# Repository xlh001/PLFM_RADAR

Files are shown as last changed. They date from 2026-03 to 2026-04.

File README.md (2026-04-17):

# AERIS-10: Open Source Pulse Linear Frequency Modulated Phased Array Radar








AERIS-10 Radar System

AERIS-10 is an open-source, low-cost 10.5 GHz phased array radar system featuring Pulse Linear Frequency Modulated (LFM) modulation. Available in two versions (3km and 20km range), it's designed for researchers, drone developers, and serious SDR enthusiasts who want to explore and experiment with phased array radar technology.

AERIS-10 Antenna Array

## 📡 Overview

The AERIS-10 project aims to democratize radar technology by providing a fully open-source, modular, and hackable radar system. Whether you're a university researcher, a drone startup, or an advanced maker, AERIS-10 offers a platform for experimenting with beamforming, pulse compression, Doppler processing, and target tracking.

## 🔬 Key Features

- **Open Source Hardware & Software** - Complete schematics, PCB layouts, firmware, and software available
- **Dual Version Availability**:
  - **AERIS-10N (Nexus)**: 3km range with 8x16 patch antenna array
  - **AERIS-10E (Extended)**: 20km range with 32x16 dielectric-filled slotted waveguide array
- **Full Electronic Beam Steering** - ±45° electronic steering in elevation and azimuth
- **Advanced Signal Processing** - On-board FPGA handles pulse compression, Doppler FFT, MTI, and CFAR
- **Python GUI** - User-friendly interface with map integration
- **GPS/IMU Integration** - Real-time position and attitude correction
- **Modular Design** - Separate power management, frequency synthesis, and RF boards

## 🏗️ System Architecture

AERIS-10 System Diagram

### Hardware Components

The AERIS-10 main sub-systems are:

- **Power Management Board** - Supplies all necessary voltage levels to the electronics components with proper filtering and sequencing (sequencing ensured by the microcontroller)

- **Frequency Synthesizer Board** - Uses a high-performance Low Jitter Clock Generator (AD9523-1) that supplies phase-aligned clock references for:
  - RX and TX Frequency Synthesizers (ADF4382)
  - DAC
  - ADC
  - FPGA

- **Main Board** containing:
  - **DAC** - Generates the RADAR Chirps
  - **2x Microwave Mixers (LT5552)** - For up-conversion and IF-down-conversion
  - **4x 4-Channel Phase Shifters (ADAR1000)** - For RX and TX chain beamforming
  - **16x Front End Chips (ADTR1107)** - Used for both Low Noise Amplifying (RX) and Power Amplifying (TX) stages
  - **XC7A50T FPGA** - Handles RADAR Signal Processing on the upstream FTG256 board:
    - PLFM Chirps generation via the DAC
    - Raw ADC data read
    - Digital Gain Control (host-configurable gain shift)
    - I/Q Baseband Down-Conversion
    - Decimation
    - Filtering
    - Forward FFT
    - Pulse Compression
    - Doppler, MTI and CFAR processing
    - USB Interface
  - **STM32F746xx Microcontroller** - Used for:
    - Power-up and power-down sequencing (see Power Management Excel File)
    - FPGA communication
    - Setup and Interface with:
      - Clock Generator (AD9523-1)
      - 2x Frequency Synthesizers (ADF4382)
      - 4x 4-Channel Phase Shifters (ADAR1000) for RADAR pulse sequencing
      - 2x ADS7830 8-channel I²C ADCs (Main Board, U88 @ 0x48 / U89 @ 0x4A) for 16x Idq measurement, one per PA channel, each sensed through a 5 mΩ shunt on the PA board and an INA241A3 current-sense amplifier (x50) on the Main Board
      - 2x DAC5578 8-channel I²C DACs (Main Board, U7 @ 0x48 / U69 @ 0x49) for 16x Vg control, one per PA channel; closed-loop calibrated at boot to the target Idq
      - GPS module (UM982) for GUI map centering and per-detection position tagging
      - GY-85 IMU for pitch/roll correction of target coordinates
      - BMP180 Barometer
      - Stepper Motor
      - 1x ADS7830 8-channel I²C ADC (Main Board, U10) reading 8 thermistors for thermal monitoring; a single GPIO (EN_DIS_COOLING) switches the cooling fans on when any channel exceeds the threshold
      - RF switches

- **16x Power Amplifier Boards** - Used only for AERIS-10E version, featuring 10Watt QPA2962 GaN amplifier for extended range

- **Antenna Arrays**:
  - **AERIS-10N (Nexus)** - 8x16 patch antenna array
  - **AERIS-10X (Extended)** - 32x16 dielectric-filled slotted waveguide antenna array

- **Miscellaneous Components**:
  - Slip-Ring
  - Stepper Motor and drivers
  - Cooling Fans
  - Enclosure

### Processing Pipeline

1. **Waveform Generation** - DAC creates LFM chirps
2. **Up/Down Conversion** - LT5552 mixers handle frequency translation
3. **Beam Steering** - ADAR1000 phase shifters control 16 elements
4. **Signal Processing (FPGA)**:
   - Raw ADC data capture
   - I/Q baseband down-conversion
   - Decimation & filtering (CIC/FIR)
   - Pulse compression
   - Doppler FFT processing
   - MTI & CFAR detection
5. **System Management (STM32)**:
   - Power sequencing
   - Peripheral configuration
   - GPS/IMU integration
   - Stepper motor control
6. **Visualization (Python GUI)**:
   - Real-time target plotting
   - Map integration
   - Radar control interface

AERIS-10 GUI Demo

## 📊 Technical Specifications

| Parameter | AERIS-10N (Nexus) | AERIS-10X (Extended) |
|---|---|---|
| **Frequency** | 10.5 GHz | 10.5 GHz |
| **Max Range** | 3 km | 20 km |
| **Antenna** | 8x16 Patch Array | 32x16 Slotted Waveguide |
| **Beam Steering** | Electronic (±45°) | Electronic (±45°) |
| **Mechanical Scan** | 360° (stepper motor) | 360° (stepper motor) |
| **Output Power** | ~1W×16 | 10W×16 (GaN amplifier) |
| **Processing** | FPGA + STM32 | FPGA + STM32 |

## 🚀 Getting Started

### 🧹 Repository File Placement Policy

To keep the repository root clean and make artifacts easy to find, place generated files in the following locations:

- **Published reports (tracked, GitHub Pages):** `docs/`
  - Example: `docs/AERIS_Simulation_Report_v2.pdf`
- **Simulation-generated outputs (local, gitignored):** `5_Simulations/generated/`
  - Plots, scenario outputs, temporary analysis directories
- **FPGA/Vivado generated artifacts (local, gitignored):** `9_Firmware/9_2_FPGA/reports/`
  - VCD/VVP dumps, temporary CSVs, local report snapshots
- **Reusable FPGA automation scripts (tracked):** `9_Firmware/9_2_FPGA/scripts/`
  - TCL flows, helper scripts used by build/bring-up

**Do not leave generated artifacts in the repository root.**

### Prerequisites

- Basic understanding of radar principles
- Experience with PCB assembly (for hardware build)
- Python 3.8+ for the GUI software
- FPGA development tools (Vivado) for signal processing modifications

### Hardware Assembly

1. **Order PCBs**: Production outputs are under `/4_Schematics and Boards Layout/4_7_Production Files`
2. **Source Components**: BOM/CPL files are co-located under `/4_Schematics and Boards Layout/4_7_Production Files`
3. **Assembly**: Use the schematics in `/4_Schematics and Boards Layout/4_6_Schematics` together with the production outputs above; a standalone assembly guide is not currently tracked
4. **Antenna**: Choose appropriate array files for your target variant
5. **Enclosure**: Mechanical drawings currently live in `/8_Utils/Mechanical_Drawings`

## 📜 License

This project is open-source but uses **different licenses for hardware and software** to ensure proper legal coverage.

### Hardware Documentation
The hardware design files—including:
- Schematics and PCB layouts (in `/4_Schematics and Boards Layout`)
- Bill of Materials (BOM) files
- Gerber files and manufacturing outputs
- Mechanical drawings and enclosure designs

are licensed under the **CERN Open Hardware Licence Version 2 – Permissive (CERN-OHL-P)** .

This is a hardware-specific license that:
- ✅ Clearly defines "Hardware," "Documentation," and "Products"
- ✅ Includes explicit patent protection for contributors and users
- ✅ Provides stronger liability limitations (important for high-power RF)
- ✅ Aligns with professional open-hardware standards (CERN, OSHWA)

You may use, modify, and sell products based on these designs, provided you:
- Maintain the original copyright notices
- Distribute any modified designs under the same license
- Make your modifications available in Source format

### Software and Firmware
The software components—including:
- FPGA code (VHDL/Verilog in `/9_Firmware`)
- Microcontroller firmware (STM32)
- Python GUI and utilities

remain under the **MIT License** for maximum flexibility.

### Full License Texts
- The complete CERN-OHL-P license text is in the `LICENSE` file
- MIT license terms apply to software where not otherwise specified

### Why This Change?
Originally, the entire project used the MIT license. The community (special thanks to gmaynez!) pointed out that MIT lacks legal protections needed for physical hardware. The switch to CERN-OHL-P ensures the project is properly protected while maintaining the same permissive spirit.

## 📚 Documentation

Comprehensive documentation is available in the `/docs` folder and served via GitHub Pages at [https://NawfalMotii79.github.io/PLFM_RADAR/docs/](https://NawfalMotii79.github.io/PLFM_RADAR/docs/):

- [System Architecture](/docs/architecture.html)
- [Implementation Log](/docs/implementation-log.html)
- [Hardware Bring-Up Guide](/docs/bring-up.html)
- [Test Reports](/docs/reports.html)
- [Release Notes](/docs/release-notes.html)

## 🤝 Contributing

We welcome contributions! Please see our [Contributing Guidelines](/CONTRIBUTING.md) for details on repo layout, branch workflow, and basic PR checks.

Areas where help is especially appreciated:
- **RF Engineers**: Review designs, optimize antenna performance
- **FPGA Developers**: Optimize signal processing pipeline
- **Software Developers**: Enhance Python GUI and SDK
- **Beta Testers**: University researchers, drone startups, advanced makers

## 📞 Contact & Collaboration

I welcome serious inquiries from researchers, engineers, and potential collaborators. However, due to the high volume of interest in this project, please understand that I cannot guarantee a response to every message.

- **Technical questions or bug reports**: Please [open a GitHub issue](https://github.com/NawfalMotii79/PLFM_RADAR/issues) so the whole community can benefit from the discussion.
- **Collaboration, licensing, or business inquiries**: 📧 nawfal.motii.33 [at] gmail [dot] com

## 💰 Sponsors

PCBWay Sponsor Logo

---

**Star ⭐ this repository if you're interested in open-source radar technology!**

*Note: This is an active development project. Some features are still in progress. Check the issues page for known limitations and upcoming features.*

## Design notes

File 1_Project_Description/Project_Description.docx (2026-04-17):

TITLE: Open Source Pulse Linear Frequency Modulated Phased Array RADAR
Reference:
Date:
Original Proposal Date:

## 1.0 PROJECT DESCRIPTION

An open-source, low-cost 10.5 GHz phased array radar with phased array antenna and Pulse LFM modulation—available in 3km and 20km range versions. For researchers, drone developers, and serious SDR enthusiasts.

## 2.0 TECHNICAL SPECIFICATIONS

### 2.1 System Architecture Overview

- The AERIS-10 comes in 2 versions:
  - AERIS-10N (Nexus) with Range up to 3Km
  - AERIS-10X (Extended) with scanning Range up to 20Km
- Frequency: 10.5GHz
- Antenna Type: 8x16 patch antenna array for the Nexus and 32x16 dielectric-filled slotted waveguide antenna array for the Extended version.
- Electronically controlled Elevation and Azimuth Beam steering. (The prototype uses the 16 antenna elements to steer the Elevation beam and the Azimuth is performed using a stepper motor; but the designed system can be hacked to control both Elevation and Azimuth electronically.
- Output: Range & Doppler of Multi-Targets
- Interface: A GUI written in Python

Current Status: Alpha Prototype

For sake of testing, validating and optimizing the cost of the prototype, this late has been designed using one PCB for:
- The Power supply management
- The Digital components
- The Analog and mixed signal components
- The RF parts

This won’t be the case for the mass production system, where separated modules would be used to reduce EMI and enhance the signals integrity; also a more professional clock source and frequency synthesizer would be used. The new schematics, PCB layout and firmware are already available

Understanding the System Hardware:

The AERIS-10 main sub-systems are:

- A Power Management Board that supplies all the necessary voltage levels to the electronics components with proper filtering and sequencing (This late is ensured by the microcontroller)
- A Frequency Synthesizer Board using a high performance Low Jitter Clock Generator (AD9523-1) that supplies phased aligned clock references for the:
  - RX and TX Frequency Synthesizers (ADF4382)
  - DAC
  - ADC
  - FPGA
- A Main Board containing:
  - A DAC to generate the RADAR Chirps
  - 2 Microwave Mixers (LT5552) for up-conversion and IF-down-conversion
  - 4 4-Channels Phase Shifters (ADAR1000) for the RX and TX chain
  - 16 Front End chips (ADTR1107) used for Both Low Noise Amplifying (RX) and Power Amplifying (TX) Stages
  - An XC7A100T FPGA used for RADAR Signal Processing:
    - PLFM Chirps generation via the DAC
    - Raw ADC data read
    - AGC
    - I/Q Baseband Down-Conversion
    - Decimation
    - Filtering
    - Forward FFT
    - Pulse Compression
    - Doppler, MTI and CFAR processing
    - USB Interface
  - An STM32F746xx Microcontroller used to:
    - Ensure the proper powering up and down sequencing (Check the Power Management Excel File)
    - Communicate with the FPGA
    - Setup and Interface with the following components:
      - The Clock Generator (AD9523-1)
      - The 2 Frequency Synthesizers (ADF4382)
      - The 4 4-Channels Phase Shifters (ADAR1000) for proper RADAR pulse sequencing
      - The 2 ADS7830 ADCs used on the 16 Power Amplifier Boards to measure Idq
      - The 2 DAC5578 used on the 16 Power Amplifier Boards to control Vg
      - The GPS used to set the center of the map on the GUI
      - The GY_85 IMU to apply pitch and roll correction to the processed target longitude and latitude
      - The BMP180 Barometer
      - The Stepper Motor
      - The 8 ADS7830 Temperature Sensors used to activate the Cooling Fans
      - RF switches
- 16 Power Amplifier Boards used only for the AERIS-10E where a 10Watt QPA2962 GaN amplifier has been chosen to extend the RADAR Range
- 8x16 patch antenna array board for the Nexus and 32x16 dielectric-filled slotted waveguide antenna array for the Extended version
- Miscellaneous (Slip-Ring, Stepper Motor and its drivers, Cooling Fan, Enclosure…)

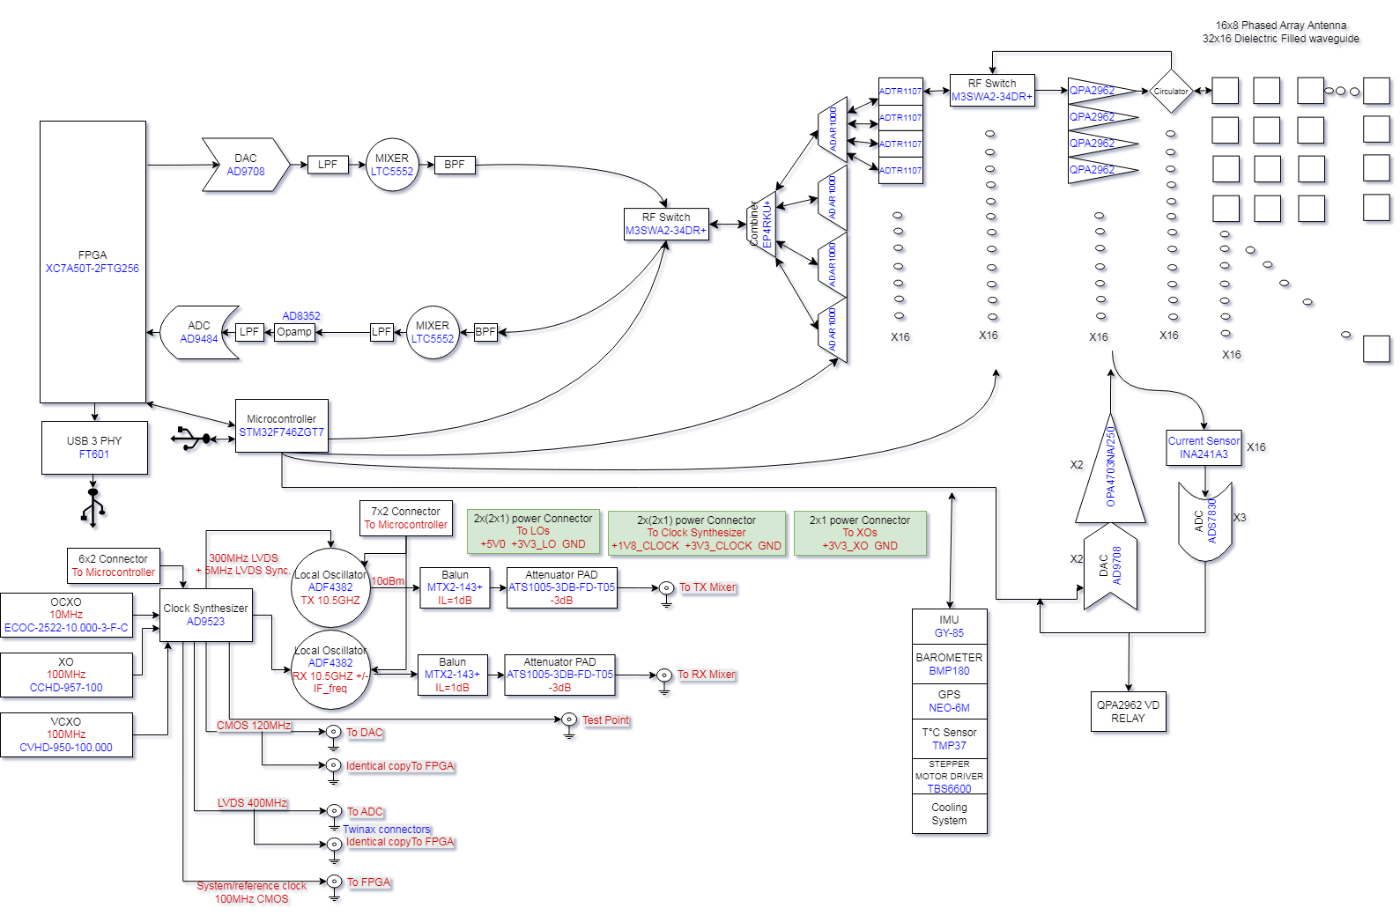
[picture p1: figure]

### 2.4 Software & Processing

The AERIS-10 radar system is built around three core processing elements working in concert: an STM32 microcontroller handling system management and peripherals, an FPGA executing real-time signal processing, and a Graphical User Interface (GUI) for user control and data visualization. The following describes the complete boot sequence and operational loop that governs how the system wakes, calibrates, and begins scanning.

### System Boot and Initialization

When power is first applied, the STM32 microcontroller begins a carefully sequenced startup routine designed to bring all subsystems online in the correct order, ensuring stable power and clock references before any RF activity begins.

The first critical step is waiting for the OCXO (Oven-Controlled Crystal Oscillator) to reach thermal stability. This high-precision frequency reference requires approximately three minutes to warm up and stabilize—without this wait, the entire radar's frequency accuracy would drift, compromising range resolution and target detection.

Once the OCXO is stable, the STM32 manages voltage sequencing for the system's clock generator, the AD9523. This ensures that power rails reach their correct levels in the proper order before the device is initialized. The STM32 then configures the AD9523, setting up the planned clock distribution that will drive the FPGA and all RF components with precise, phase-aligned timing.

With clocks established, the STM32 sequences power for the FPGA itself, then proceeds to initialize the remaining peripheral systems:

- The GPS module begins acquiring satellite locks
- The IMU (Inertial Measurement Unit) and barometer are initialized for attitude and altitude sensing
- Two ADF4382 frequency synthesizers (one for transmit, one for receive) are configured
- Four ADAR1000 beamforming chips are initialized to control the 16 phased array elements

At this point, all hardware is ready and the system enters a waiting state, listening for the start command from the GUI.

### GUI Connection and System Arming

The operator interacts with the system through a custom Graphical User Interface running on a connected computer. When the user is ready to begin operation, they press the Start button on the GUI.

The GUI immediately transmits a specific start flag packet to the STM32—a predefined sequence of bytes {23, 46, 158, 237} that serves as a handshake to confirm communication is established. Following this flag, the GUI sends the full operational settings for the upcoming radar scan (waveform parameters, scan pattern, range settings, etc.).

The STM32 acknowledges these settings and begins actively monitoring the GPS data stream. It waits for a valid data lock, then begins sending modulated position streams back to the GUI containing longitude, latitude, and altitude information. The GUI receives these streams and uses the coordinates to center its map display on the radar's current location—giving the operator immediate spatial context for any detected targets.

### Attitude Determination and Mechanical Alignment

While maintaining GPS position updates, the STM32 continuously reads raw data from the IMU and barometer. It processes the IMU data to calculate pitch, roll, and yaw angles, while the barometer provides a secondary altitude reference.

With yaw (heading) known, the STM32 commands the stepper motor to rotate the antenna assembly to align with yaw = 0° (typically true north or a defined reference). This mechanical alignment ensures that all subsequent electronically-steered beams are referenced to a consistent absolute direction.

### Transmit and Receive Chain Configuration

Before any radar pulses are sent, the RF front-end must be precisely tuned. The STM32 configures the two ADF4382 frequency synthesizers—one set to the transmit frequency, the other to the receive frequency. Critically, it then executes a phase synchronization routine between these two synthesizers, ensuring that transmit and receive local oscillators are phase-coherent. This coherence is essential for Doppler processing and coherent pulse compression.

### The Scanning Loop: A Three-Level Nested Structure

The AERIS-10's scanning pattern is organized as a three-level nested loop, controlling:

1. Chirp sequence index (m) – Individual frequency ramps within a burst
2. Beam steering index (n) – Electronic steering across 32 elevation/azimuth positions
3. Mechanical azimuth index (y) – Physical rotation across 50 positions per revolution

This structure allows the system to build a complete volumetric scan through a combination of electronic beam steering (fast, within the pulse repetition interval) and mechanical rotation (slow, covering 360 degrees).

#### Loop Variables Defined

- m = Chirp number within a burst. Each burst consists of 32 chirps, organized as: *16 chirps at PRF1 (pulse repetition frequency 1) with duration T1, followed by a guard interval of 175.4µs, then 16 chirps at PRF2 with duration T2*
- n = Electronic steering index, ranging from 1 to 32. This corresponds to beam positions in elevation (or azimuth, depending on scan mode), controlled by phase settings on the ADAR1000 beamforming chips.
- y = Mechanical azimuth index, ranging from 1 to 50. The stepper motor moves the antenna to 50 discrete positions per full revolution, providing mechanical scanning in azimuth while electronics handle fast steering in the orthogonal plane.

### The Operational Loop

The loop begins with the STM32 commanding the stepper motor to move to the first azimuth position (y=1). Once the mechanical position is settled:

1. The STM32 sets the ADAR1000 phase shifters to the values corresponding to beam position n
2. It manages voltage sequencing for the ADTR1107s (RF switches) and the RF power amplifiers, ensuring they power up cleanly
3. It sends a flag to the FPGA indicating transmit mode and configures the ADAR1000s for transmission
4. The FPGA generates the chirp waveform through its DAC, driving the transmit array
5. Immediately after transmission, the FPGA signals the STM32 to switch to receive mode
6. The STM32 reconfigures the ADAR1000s for reception
7. The FPGA captures the returning echoes through its ADCs and begins the signal processing pipeline:
  - Down-conversion of the IF signal to baseband
  - Filtering
  - Extraction of I/Q components (using CIC filters, FIR filters, and NCO)
  - Pulse compression
  - Per-range Doppler FFT
  - Moving Target Indication (MTI)
  - Constant False Alarm Rate (CFAR) detection
  - Emission of detection reports (including small Range-Doppler thumbnails)
8. Processed radar data is sent from the FPGA to the GUI via FTDI interface
9. The GUI receives the data and updates its plots in real-time, displaying detected targets overlaid on the map

### Loop Iteration and Scan Completion

After completing the processing for chirp m, the system increments m and returns to step 34 (DAC chirp generation). This continues until m exceeds 32, at which point:

- m resets to 1
- n increments (move to next electronic beam position)
- The loop returns to step 29 (set new ADAR1000 phase values)

When n exceeds 32 (all electronic beam positions completed), then:

- n resets to 1
- y increments (move stepper motor to next mechanical azimuth position)
- If y exceeds 50 (full revolution completed), y resets to 1 and the scan continues indefinitely or until stopped by the operator

This continuous loop builds a complete 3D radar picture, with electronic steering providing fast elevation/azimuth coverage and mechanical rotation providing full 360-degree azimuth scanning.

### Summary

The AERIS-10's operational flow represents a sophisticated orchestration of multiple subsystems:

- STM32 handles the "conductor" role—sequencing power, configuring peripherals, managing the stepper motor, and coordinating mode switches
- FPGA executes the "orchestra"—generating waveforms, capturing echoes, and running the intense signal processing pipeline
- GUI provides the "audience view"—displaying maps, targets, and enabling operator control

This division of labor allows each processor to focus on what it does best, creating a coherent, high-performance radar system that remains flexible and programmable through its open architecture.

What's Working:

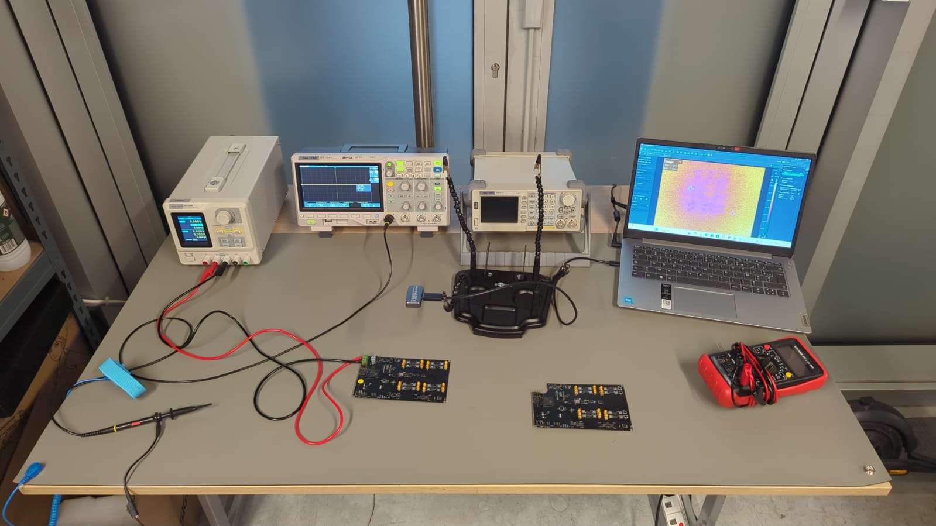
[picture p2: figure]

- Beam formation from 16x8 array
- Electronic steering ±45° elevation
- Pulse LFM generation and reception
- Basic target detection to 1km
- Raw data capture and processing via the FPGA:
  - FM Chirp generation via the DAC
  - Raw ADC data read
  - AGC
  - I/Q Base Band Down-Conversion
  - Decimation
  - Filtering
  - Forward FFT
  - Pulse Compression
  - Doppler, MTI and CFAR processing

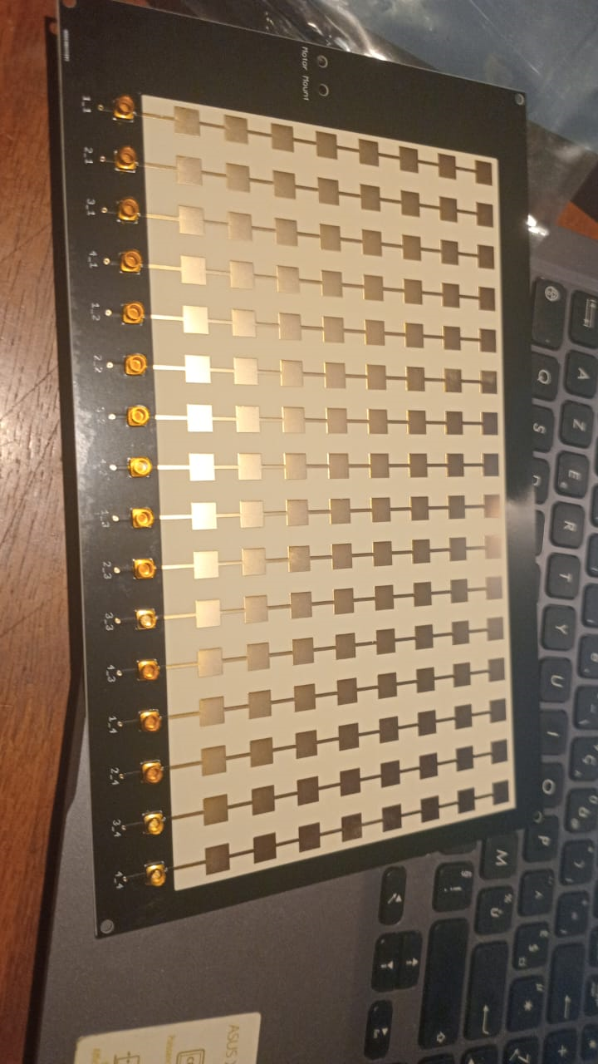
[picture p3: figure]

What's in Progress:

- Performing the RADAR processing using the python GUI rather than the FPGA and benchmarking the 2 approaches.
- Using multiple synchronized RADAR boards to enhance the beam steering resolution and Range.
- Crowd funding campaign launch

Get Involved:

I'm actively seeking:

- Beta testers: (university researchers, drone startups, advanced makers)

- RF engineers to review designs

- FPGA developers for signal processing optimization

- Software developers for the Python/C++ SDK

Project Link: https://hackaday.io/project/205190-open-source-plfm-radar-up-to-20km-range

http://www.github.com/NawfalMotii79/PLFM_RADAR

ABAC INDUSTRY SARL AU /R.C. n° 515463 / I.T.P. n° 34262538 / n° ICE 002911762000053 / IF n° 50499079 Adresse: 46 BD ZERKTOUNI ETG 5 N17 CO DOWORK CASABLANCA MAROC Tel: +212 (0) 786433177 email: nawfal.motii.33@gmail.com web site: www.abac-industry.com

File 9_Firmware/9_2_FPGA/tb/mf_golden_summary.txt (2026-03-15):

========================================================================
Matched Filter Golden Reference Summary
Operation: output = IFFT( FFT(signal) * conj(FFT(reference)) )
FFT length: 1024
========================================================================

------------------------------------------------------------------------
Case 1: DC autocorrelation: signal=ref=DC(I=0x1000,Q=0). Expected: large peak at bin 0, zero elsewhere. Peak will saturate to 32767 due to 16-bit clamp.
------------------------------------------------------------------------
  Peak bin:              0
  Peak magnitude (float):17179869184.000000
  Peak I (float):        17179869184.000000
  Peak Q (float):        0.000000
  Peak I (quantized):    32767
  Peak Q (quantized):    0
  Files:
    mf_golden_sig_i_case1.hex
    mf_golden_sig_q_case1.hex
    mf_golden_ref_i_case1.hex
    mf_golden_ref_q_case1.hex
    mf_golden_out_i_case1.hex
    mf_golden_out_q_case1.hex

------------------------------------------------------------------------
Case 2: Tone autocorrelation: signal=ref=tone(bin 5, amp 8000). Expected: peak at bin 0 (autocorrelation peak at zero lag).
------------------------------------------------------------------------
  Peak bin:              0
  Peak magnitude (float):65536183223.999985
  Peak I (float):        65536183223.999985
  Peak Q (float):        -0.000000
  Peak I (quantized):    32767
  Peak Q (quantized):    0
  Files:
    mf_golden_sig_i_case2.hex
    mf_golden_sig_q_case2.hex
    mf_golden_ref_i_case2.hex
    mf_golden_ref_q_case2.hex
    mf_golden_out_i_case2.hex
    mf_golden_out_q_case2.hex

------------------------------------------------------------------------
Case 3: Shifted tone: signal=tone(bin 5), ref=tone(bin 5) delayed by 3 samples. Cross-correlation peak should shift to indicate the delay.
------------------------------------------------------------------------
  Peak bin:              253
  Peak magnitude (float):65536183223.999992
  Peak I (float):        0.000005
  Peak Q (float):        65536183223.999992
  Peak I (quantized):    0
  Peak Q (quantized):    32767
  Files:
    mf_golden_sig_i_case3.hex
    mf_golden_sig_q_case3.hex
    mf_golden_ref_i_case3.hex
    mf_golden_ref_q_case3.hex
    mf_golden_out_i_case3.hex
    mf_golden_out_q_case3.hex

------------------------------------------------------------------------
Case 4: Impulse autocorrelation: signal=ref=delta(n=0, I=0x7FFF). Expected: scaled delta at bin 0 (will saturate to 32767). All other bins should be zero.
------------------------------------------------------------------------
  Peak bin:              0
  Peak magnitude (float):1073676289.000000
  Peak I (float):        1073676289.000000
  Peak Q (float):        0.000000
  Peak I (quantized):    32767
  Peak Q (quantized):    0
  Files:
    mf_golden_sig_i_case4.hex
    mf_golden_sig_q_case4.hex
    mf_golden_ref_i_case4.hex
    mf_golden_ref_q_case4.hex
    mf_golden_out_i_case4.hex
    mf_golden_out_q_case4.hex

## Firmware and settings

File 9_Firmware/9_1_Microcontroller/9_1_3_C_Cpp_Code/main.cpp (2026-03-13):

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
/* Includes ------------------------------------------------------------------*/
#include "main.h"
#include "usb_device.h"
#include "USBHandler.h"
#include "usbd_cdc_if.h"
#include "adar1000.h"
#include "ADAR1000_Manager.h"
extern "C" {
#include "ad9523.h"
}
#include "no_os_delay.h"
#include "no_os_alloc.h"
#include "no_os_print_log.h"
#include "no_os_error.h"
#include "no_os_units.h"
#include "no_os_dma.h"
#include "no_os_spi.h"
#include "no_os_uart.h"
#include "no_os_util.h"
#include <stdint.h>
#include <errno.h>
#include <math.h>
#include <stdio.h>
#include <string.h>
#include <inttypes.h>
#include <iostream>
#include <vector>
#include "stm32_spi.h"
#include "stm32_delay.h"
#include "TinyGPSPlus.h"
extern "C" {
#include "GY_85_HAL.h"
}
#include "BMP180.h"
extern "C" {
#include "platform_noos_stm32.h"
}
extern "C" {

#include "adf4382a_manager.h"
#include "adf4382.h"
#include "no_os_delay.h"
#include "no_os_error.h"
}
#include <cmath>
#include "DAC5578.h"
#include "ADS7830.h"
#include "gps_handler.h"

#include "stm32f7xx_hal.h"




/* USER CODE BEGIN PD */


/* -------- GPIO index mapping for no-OS interface -------- */
#define GPIO_IDX_TX_CS       0
#define GPIO_IDX_RX_CS       1
#define GPIO_IDX_TX_DELSTR   2
#define GPIO_IDX_TX_DELADJ   3
#define GPIO_IDX_RX_DELSTR   4
#define GPIO_IDX_RX_DELADJ   5
#define GPIO_IDX_TX_CE       6
#define GPIO_IDX_RX_CE       7
#define GPIO_IDX_SW_SYNC     8

/* USER CODE END PD */


I2C_HandleTypeDef hi2c1;
I2C_HandleTypeDef hi2c2;
I2C_HandleTypeDef hi2c3;

SPI_HandleTypeDef hspi1;
SPI_HandleTypeDef hspi4;

TIM_HandleTypeDef htim1;

UART_HandleTypeDef huart5;
UART_HandleTypeDef huart3;

/* USER CODE BEGIN PV */
// The TinyGPSPlus object
TinyGPSPlus gps;

// Global data structures
GPS_Data_t current_gps_data = {0};

// Global USB handler
USBHandler usbHandler;
extern USBD_HandleTypeDef hUsbDeviceFS;

// Buffer for USB reception
uint8_t usb_rx_buffer[64];

//IMU variable
GY85_t imu;

float Pitch_Sensor, Yaw_Sensor, Roll_Sensor;

float abias[3] = {-0.108, -0.038, -0.006}, gbias[3] = {-10, 6, -12}, mbias[3]={0.0,0.0,0.0};
float M11=1.0,  M12=-0.0,  M13=0.0,
      M21=0.0,  M22=1.0,   M23=0.0,
      M31=0.0,  M32=-0.0,  M33=1.0;
float ax, ay, az, gx, gy, gz, mx, my, mz,mxc,myc,mzc; // variables to hold latest sensor data values
float q[4] = {1.0f, 0.0f, 0.0f, 0.0f};    // vector to hold quaternion
float temperature;
float Mag_Declination = -0.61; //0°

float RxAcc,RyAcc,RzAcc;
float Rate_Ayz_1,Rate_Axz_1,Rate_Axy_1;
float Axz_1,Ayz_1,Axy_1, Axz_0,Ayz_0,Axy_0;
float RxEst_0,RyEst_0,RzEst_0, RxEst_1,RyEst_1,RzEst_1,Azr_Est;
float RxGyro,RyGyro,RzGyro, R_Est;

unsigned long now_timeperiod;
unsigned long lasttime_timeperiod = 0;
int Time_Period = 0;

//Barometer BMP180

/*resolution:
BMP180_ULTRALOWPOWER - pressure oversampled 1 time  & power consumption 3μA
BMP180_STANDARD      - pressure oversampled 2 times & power consumption 5μA
BMP180_HIGHRES       - pressure oversampled 4 times & power consumption 7μA
BMP180_ULTRAHIGHRES  - pressure oversampled 8 times & power consumption 12μA, library default
*/
BMP180 myBMP(BMP180_ULTRAHIGHRES);
float RADAR_Altitude;

//GPS
double RADAR_Longitude = 0;
double RADAR_Latitude = 0;

extern uint8_t GUI_start_flag_received;


//RADAR
// Radar parameters
const int m_max = 32;  // Number of chirps per beam position
const int n_max = 31;   // Number of beam positions
const float T1 = 30.0f; // Chirp duration in microseconds
const float PRI1 = 167.0f; // Pulse repetition interval in microseconds
const float T2 = 0.5f;  // Short chirp duration in microseconds
const float PRI2 = 175.0f; // Short PRI in microseconds
const float Guard = 175.4f; // Guard time in microseconds

uint8_t	m = 1; // m = N° of chirp/ position = 16 (made of T1 and PRF1)+ Guard = 175µs +16 (made of T2 and PRF2)
uint8_t	n = 1; // n =[1-31] N° of elevations/azimuth
uint8_t	y = 1;// y = N° of azimuths/revolution = 50 controlled by a microcontroller connected to a stepper motor
uint8_t y_max = 50;// y = N° of azimuths/revolution
uint64_t IF_freq = 120000000ULL;//120MHz

#define PowerAmplifier 1

//Stepper Motor
float Stepper_steps = 200.0f;//step per revolution

// DAC5578 handles (RF Power Amplifier DAC controlling Vg)
DAC5578_HandleTypeDef hdac1, hdac2;
/* Phase accumulators */
float phase_dac1[8] = {0};
float phase_dac2[8] = {0};
const uint32_t sampleRate = 370;    // Sample rate in Hz
const uint32_t period = 2700;       // Period in microseconds
uint8_t DAC_val = 126;

// ADC handles (RF Power Amplifier ADC measuring Idq)
ADS7830_HandleTypeDef hadc1, hadc2;
uint8_t adc1_readings[8] = {0};
uint8_t adc2_readings[8] = {0};
float Idq_reading[16]={0.0f};


// Global manager instance ADF4382A
ADF4382A_Manager lo_manager;
extern SPI_HandleTypeDef hspi4;

//ADAR1000

ADAR1000Manager adarManager;
static uint8_t matrix1[15][16];
static uint8_t matrix2[15][16];
static uint8_t vector_0[16] = {0,0,0,0,0,0,0,0,0,0,0,0,0,0,0,0};

/* Radar parameters
const int m_max = 32;  // Number of chirps per beam position
const int n_max = 31;   // Number of beam positions
const float T1 = 30.0f; // Chirp duration in microseconds
const float PRI1 = 167.0f; // Pulse repetition interval in microseconds
const float T2 = 0.5f;  // Short chirp duration in microseconds
const float T2 = 175.0f; // Short PRI in microseconds
const float Guard = 175.40f; // Guard time in microseconds*/

//Temperature Sensors
ADS7830_HandleTypeDef hadc3;
float Temperature_1 = 0.0f, Temperature_2 = 0.0f, Temperature_3 = 0.0f, Temperature_4 = 0.0f;
float Temperature_5 = 0.0f, Temperature_6 = 0.0f, Temperature_7 = 0.0f, Temperature_8 = 0.0f;

// Phase differences for 31 beam positions
const float phase_differences[31] = {
    160.0f, 80.0f, 53.333f, 40.0f, 32.0f, 26.667f, 22.857f, 20.0f, 17.778f, 16.0f,
    14.545f, 13.333f, 12.308f, 11.429f, 10.667f, 0.0f,
    -10.667f, -11.429f, -12.308f, -13.333f, -14.545f, -16.0f, -17.778f, -20.0f,
    -22.857f, -26.667f, -32.0f, -40.0f, -53.333f, -80.0f, -160.0f
};

// Convenience HAL wrappers for AD9523 control pins (GPIOF as you said)
static inline void AD9523_PD(bool v)        { HAL_GPIO_WritePin(GPIOF, AD9523_PD_Pin, v ? GPIO_PIN_SET : GPIO_PIN_RESET); }
static inline void AD9523_REF_SEL(bool v)   { HAL_GPIO_WritePin(GPIOF, AD9523_REF_SEL_Pin, v ? GPIO_PIN_SET : GPIO_PIN_RESET); }
static inline void AD9523_SYNC_PULSE(void)  { HAL_GPIO_WritePin(GPIOF, AD9523_SYNC_Pin, GPIO_PIN_SET); HAL_Delay(1); HAL_GPIO_WritePin(GPIOF, AD9523_SYNC_Pin, GPIO_PIN_RESET); }
static inline void AD9523_RESET_ASSERT()    { HAL_GPIO_WritePin(GPIOF, AD9523_RESET_Pin, GPIO_PIN_RESET); } // check polarity
static inline void AD9523_RESET_RELEASE()   { HAL_GPIO_WritePin(GPIOF, AD9523_RESET_Pin, GPIO_PIN_SET); }
static inline void AD9523_CS(bool v)        { HAL_GPIO_WritePin(GPIOF, AD9523_CS_Pin, v ? GPIO_PIN_SET : GPIO_PIN_RESET); }
static inline void AD9523_EEPROM_SEL(bool v){ HAL_GPIO_WritePin(GPIOF, AD9523_EEPROM_SEL_Pin, v ? GPIO_PIN_SET : GPIO_PIN_RESET); }

/* USER CODE END PV */

void SystemClock_Config(void);
void PeriphCommonClock_Config(void);
static void MPU_Config(void);
static void MX_GPIO_Init(void);
static void MX_TIM1_Init(void);
static void MX_I2C1_Init(void);
static void MX_I2C2_Init(void);
static void MX_I2C3_Init(void);
static void MX_SPI1_Init(void);
static void MX_SPI4_Init(void);
static void MX_UART5_Init(void);
static void MX_USART3_UART_Init(void);
/* USER CODE BEGIN PFP */

// Function prototypes
void systemPowerUpSequence();
void systemPowerDownSequence();
void initializeBeamMatrices();
void runRadarPulseSequence();
void executeChirpSequence(int num_chirps, uint32_t T1, uint32_t PRI1, uint32_t T2, uint32_t PRI2);
void printSystemStatus();

//////////////////////////////////////////////
////////////////////micros()//////////////////
//////////////////////////////////////////////
unsigned long micros(void){
unsigned long Micros = __HAL_TIM_GET_COUNTER(&htim1);
return Micros; //Clock TIM1 -> AHB/APB1 is set to 72MHz/presc+1   presc = 71
}

//////////////////////////////////////////////
//////////////////Delay_us()//////////////////
//////////////////////////////////////////////

void delay_us(volatile uint32_t us){
__HAL_TIM_SET_COUNTER(&htim1,0);  // set the counter value a
while (__HAL_TIM_GET_COUNTER(&htim1) < us);  // //Clock TIMx -> AHB/APB1 is set to 72MHz/presc+1   presc = 71
}

//////////////////////////////////////////////
//////////////////delay_ns()//////////////////
//////////////////////////////////////////////
void delay_ns(uint32_t nanoseconds)
{
    // Get the starting cycle count
    uint32_t start_cycles = DWT->CYCCNT;

    // Convert nanoseconds to the number of CPU clock cycles
    // Use `SystemCoreClock` to get the current CPU frequency.
    // Use 64-bit math to prevent overflow for large nanosecond values.
    uint32_t cycles = (uint32_t)(((uint64_t)nanoseconds * SystemCoreClock) / 1000000000);

    // Busy-wait until the required number of cycles has passed
    while ((DWT->CYCCNT - start_cycles) < cycles);
}

//////////////////////////////////////////////
//////////////////////RADAR///////////////////
//////////////////////////////////////////////
uint8_t degreesTo7BitPhase(float degrees) {
    // Normalize to 0-360 range
    while(degrees < 0) degrees += 360.0f;
    while(degrees >= 360.0f) degrees -= 360.0f;

    // Convert to 7-bit (0-127)
    uint8_t phase_7bit = (uint8_t)((degrees / 360.0f) * 128.0f);

    return phase_7bit % 128;
}

extern "C" {

    // USB CDC receive callback (called by STM32 HAL)
    void CDC_Receive_FS(uint8_t* Buf, uint32_t *Len) {
        // Process received USB data
        usbHandler.processUSBData(Buf, *Len);

        // Prepare for next reception
        USBD_CDC_SetRxBuffer(&hUsbDeviceFS, &usb_rx_buffer[0]);
        USBD_CDC_ReceivePacket(&hUsbDeviceFS);
    }
}

void systemPowerUpSequence() {
    uint8_t msg[] = "Starting Power Up Sequence...\r\n";
    HAL_UART_Transmit(&huart3, msg, sizeof(msg)-1, 1000);

    // Step 1: Initialize ADTR1107 power sequence
    if (!adarManager.initializeADTR1107Sequence()) {
        uint8_t err[] = "ERROR: ADTR1107 power sequence failed!\r\n";
        HAL_UART_Transmit(&huart3, err, sizeof(err)-1, 1000);
        Error_Handler();
    }

    // Step 2: Initialize all ADAR1000 devices
    if (!adarManager.initializeAllDevices()) {
        uint8_t err[] = "ERROR: ADAR1000 initialization failed!\r\n";
        HAL_UART_Transmit(&huart3, err, sizeof(err)-1, 1000);
        Error_Handler();
    }

    // Step 3: Perform system calibration
    if (!adarManager.performSystemCalibration()) {
        uint8_t warn[] = "WARNING: System calibration issues\r\n";
        HAL_UART_Transmit(&huart3, warn, sizeof(warn)-1, 1000);
    }

    // Step 4: Set to safe TX mode
    adarManager.setAllDevicesTXMode();

    uint8_t success[] = "Power Up Sequence Completed Successfully\r\n";
    HAL_UART_Transmit(&huart3, success, sizeof(success)-1, 1000);
}

void systemPowerDownSequence() {
    uint8_t msg[] = "Starting Power Down Sequence...\r\n";
    HAL_UART_Transmit(&huart3, msg, sizeof(msg)-1, 1000);

    // Step 1: Set all devices to RX mode (safest state)
    adarManager.setAllDevicesRXMode();
    HAL_Delay(10);

    // Step 2: Disable PA power supplies
    HAL_GPIO_WritePin(EN_P_5V0_PA1_GPIO_Port, EN_P_5V0_PA1_Pin | EN_P_5V0_PA2_Pin | EN_P_5V0_PA3_Pin, GPIO_PIN_RESET);
    HAL_Delay(10);

    // Step 3: Set PA biases to safe values
    for (uint8_t dev = 0; dev < 4; dev++) {
        adarManager.adarWrite(dev, REG_PA_CH1_BIAS_ON, 0x20, BROADCAST_OFF);
        adarManager.adarWrite(dev, REG_PA_CH2_BIAS_ON, 0x20, BROADCAST_OFF);
        adarManager.adarWrite(dev, REG_PA_CH3_BIAS_ON, 0x20, BROADCAST_OFF);
        adarManager.adarWrite(dev, REG_PA_CH4_BIAS_ON, 0x20, BROADCAST_OFF);
    }
    HAL_Delay(10);

    // Step 4: Disable LNA power supply
    HAL_GPIO_WritePin(EN_P_3V3_ADTR_GPIO_Port, EN_P_3V3_ADTR_Pin, GPIO_PIN_RESET);
    HAL_Delay(10);

    // Step 5: Set LNA bias to safe value
    for (uint8_t dev = 0; dev < 4; dev++) {
        adarManager.adarWrite(dev, REG_LNA_BIAS_ON, 0x00, BROADCAST_OFF);
    }
    HAL_Delay(10);

    // Step 6: Disable switch power supplies
    HAL_GPIO_WritePin(EN_P_3V3_VDD_SW_GPIO_Port, EN_P_3V3_VDD_SW_Pin, GPIO_PIN_RESET);
    HAL_GPIO_WritePin(EN_P_3V3_SW_GPIO_Port, EN_P_3V3_SW_Pin, GPIO_PIN_RESET);
    HAL_Delay(10);

    uint8_t success[] = "Power Down Sequence Completed\r\n";
    HAL_UART_Transmit(&huart3, success, sizeof(success)-1, 1000);
}
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
int main(void)
{

  /* MPU Configuration--------------------------------------------------------*/
  MPU_Config();

  /* MCU Configuration--------------------------------------------------------*/

  /* Reset of all peripherals, Initializes the Flash interface and the Systick. */
  HAL_Init();

  /* Configure the system clock */
  SystemClock_Config();

  /* Configure the peripherals common clocks */
  PeriphCommonClock_Config();

  /* Initialize all configured peripherals */
  MX_GPIO_Init();
  MX_TIM1_Init();
  MX_I2C1_Init();
  MX_I2C2_Init();
  MX_I2C3_Init();
  MX_SPI1_Init();
  MX_SPI4_Init();
  MX_UART5_Init();
  MX_USART3_UART_Init();
  MX_USB_DEVICE_Init();
  /* USER CODE BEGIN 2 */

  HAL_TIM_Base_Start(&htim1);

  /* --- Enable DWT cycle counter for accurate microsecond delays --- */
  DWT_Init();
  //Wait for OCXO 3mn
  HAL_Delay(180000);
  HAL_GPIO_WritePin(AD9523_RESET_GPIO_Port,AD9523_RESET_Pin,GPIO_PIN_RESET);

  //Power sequencing AD9523
  HAL_GPIO_WritePin(EN_P_1V8_CLOCK_GPIO_Port,EN_P_1V8_CLOCK_Pin,GPIO_PIN_SET);
  HAL_Delay(100);
  HAL_GPIO_WritePin(EN_P_3V3_CLOCK_GPIO_Port,EN_P_3V3_CLOCK_Pin,GPIO_PIN_SET);
  HAL_Delay(100);
  HAL_GPIO_WritePin(AD9523_RESET_GPIO_Port,AD9523_RESET_Pin,GPIO_PIN_SET);
  HAL_Delay(100);

  //Set planned Clocks on AD9523
  /*
  o Channel 0 = 300MHz LVDS (ADF4382 TX)
  o Channel 1 = 300MHz LVDS (ADF4382 RX) (Phase aligned with Channel 0)
  o Channel 4 = 400MHz LVDS (ADC)
  o Channel 5 = 400MHz LVDS (FPGA_ADC)(Phase aligned with Channel 4)
  o Channel 6 = 100MHz LVCMOS (FPGA system clock)
  o Channel 7 = 20MHz LVCMOS (FPGA test)
  o Channel 8 = 60MHz LVDS (ADF4382 TX sync)
  o Channel 9 = 60MHz LVDS (ADF4382 RX sync)(Phase aligned with Channel 8)
  o Channel 10 = 120MHz LVCMOS
  o Channel 11 = 120MHz LVCMOS (Phase aligned with Channel 10)
   */


  // Ensure stm32_spi.c and stm32_delay.c are compiled and linked

  if (configure_ad9523() != 0) {
      // configuration error - handle as needed
      while (1) { HAL_Delay(1000); }
  }

  //Power sequencing FPGA
  HAL_GPIO_WritePin(EN_P_1V0_FPGA_GPIO_Port,EN_P_1V0_FPGA_Pin,GPIO_PIN_SET);
  HAL_Delay(100);
  HAL_GPIO_WritePin(EN_P_1V8_FPGA_GPIO_Port,EN_P_1V8_FPGA_Pin,GPIO_PIN_SET);
  HAL_Delay(100);
  HAL_GPIO_WritePin(EN_P_3V3_FPGA_GPIO_Port,EN_P_3V3_FPGA_Pin,GPIO_PIN_SET);
  HAL_Delay(100);


// Initialize module IMU
  if (!GY85_Init()) {
      Error_Handler();
  }
  for(int i=0; i<10;i++){
  if (!GY85_Update(&imu)) {
      Error_Handler();
  }

  ax = imu.ax;
  ay = imu.ay;
  az = imu.az;
  gx = -imu.gx;
  gy = -imu.gy;
  gz = imu.gz;
  mx = imu.mx;
  my = imu.my;
  mz = imu.mz;

  ax *= 6.10351e-5;   //2.0 / 32768.0;
  ay *= 6.10351e-5;
  az *= 6.10351e-5;

  ax -= abias[0];   // Convert to g's, remove accelerometer biases
  ay -= abias[1];
  az -= abias[2];

  gx *= 0.0152588f;   //500.0 / 32768.0;
  gy *= 0.0152588f;
  gz *= 0.0152588f;

  gx -= gbias[0];   // Convert to degrees per seconds, remove gyro biases
  gy -= gbias[1];
  gz -= gbias[2];

  mx *= 6.10351e-5;   //2.0 / 32768.0;
  my *= 6.10351e-5;
  mz *= 6.10351e-5;

  mxc = M11*(mx-mbias[0]) + M12*(my-mbias[1]) +M13*(mz-mbias[2]);
  myc = M21*(mx-mbias[0]) + M22*(my-mbias[1]) +M23*(mz-mbias[2]);
  mzc = M31*(mx-mbias[0]) + M32*(my-mbias[1]) +M33*(mz-mbias[2]);

  mx = mxc;
  my = myc;
  mz = mzc;

  float norm = sqrt((mx*mx) + (my*my) + (mz*mz));
  mx /=norm;
  my /=norm;
  mz /=norm;

  /***************************************************************/
  /*********************IMU Complementary Filter******************/
  /***************************************************************/
    RxAcc = ax;
    RyAcc = ay;
    RzAcc = az;

    Rate_Ayz_1 = gx;
    Rate_Axz_1 = gy;
    Rate_Axy_1 = gz;

    Rate_Ayz_1 = Rate_Ayz_1*0.01745;//Convertion from °/s to Radians/s
    Rate_Axz_1 = Rate_Axz_1*0.01745;
    Rate_Axy_1 = Rate_Axy_1*0.01745;

    /*Combining Accelerometer & Gyroscope Data*/
    Axz_0 = atan2(RxEst_0,RzEst_0);
    Ayz_0 = atan2(RyEst_0,RzEst_0);
    Axy_0 = atan2(RxEst_0,RyEst_0);

    now_timeperiod = micros();

    Time_Period = now_timeperiod - lasttime_timeperiod;

    Axz_1= Axz_0 + Rate_Axz_1*Time_Period*0.000001;
    Ayz_1= Ayz_0 + Rate_Ayz_1*Time_Period*0.000001;
    Axy_1= Axy_0 + Rate_Axy_1*Time_Period*0.000001;

    lasttime_timeperiod = now_timeperiod;

    RxGyro = sin(Axz_1)/(sqrt(1.0 + cos(Axz_1)*cos(Axz_1) * tan(Ayz_1)*tan(Ayz_1)));
    RyGyro = sin(Ayz_1)/(sqrt(1.0 + cos(Ayz_1)*cos(Ayz_1) * tan(Axz_1)*tan(Axz_1)));
    if(RzEst_0 >= 0){
      RzGyro = 1.0*sqrt(1 - RxGyro*RxGyro - RyGyro*RyGyro);
    }
    else {
      RzGyro = -1*sqrt(1 - RxGyro*RxGyro - RyGyro*RyGyro);
    }

    RxEst_1 = RxAcc*0.5 + RxGyro*0.5 ;// Weight of Gyro. over Acc.
    RyEst_1 = RyAcc*0.5 + RyGyro*0.5 ;
    RzEst_1 = RzAcc*0.5 + RzGyro*0.5 ;

    R_Est = sqrt(RxEst_1*RxEst_1+RyEst_1*RyEst_1+RzEst_1*RzEst_1);

    Pitch_Sensor = atan2(RxEst_1,sqrt(RyEst_1*RyEst_1)+(RzEst_1*RzEst_1))*180/PI;
    Roll_Sensor = atan2(RyEst_1,sqrt(RxEst_1*RxEst_1)+(RzEst_1*RzEst_1))*180/PI;

    float magRawX = mx*cos(Pitch_Sensor*PI/180.0f)  - mz*sin(Pitch_Sensor*PI/180.0f);
	float magRawY = mx*sin(Roll_Sensor*PI/180.0f)*sin(Pitch_Sensor*PI/180.0f) + my*cos(Roll_Sensor*PI/180.0f)- mz*sin(Roll_Sensor*PI/180.0f)*cos(Pitch_Sensor*PI/180.0f);
    Yaw_Sensor = (180*atan2(magRawY,magRawX)/PI) - Mag_Declination;

    if(Yaw_Sensor<0)Yaw_Sensor+=360;
    RxEst_0 = RxEst_1;
    RyEst_0 = RyEst_1;
    RzEst_0 = RzEst_1;

    HAL_Delay(300);

  }

    ///////////////////////////////////////////////////////////////////////////////////
    ///////////////////////////////////BAROMETER BMP180////////////////////////////////
    ///////////////////////////////////////////////////////////////////////////////////
  	for(int i = 0; i<5 ; i++){
		float BMP_Perssure = myBMP.getPressure();
		RADAR_Altitude = 44330*(1-(pow((BMP_Perssure/101325),(1/5.255))));
		HAL_Delay(100);
  	}

    ///////////////////////////////////////////////////////////////////////////////////
    ///////////////////////////////////////ADF4382/////////////////////////////////////
    ///////////////////////////////////////////////////////////////////////////////////
    printf("Starting ADF4382A Radar LO System...\n");
    printf("Using SPI4 with TIMED SYNCHRONIZATION (60 MHz clocks)\n");

    // Initialize LO manager with TIMED synchronization
    int ret = ADF4382A_Manager_Init(&lo_manager, SYNC_METHOD_TIMED);
    // Set phase shift (e.g., 500 ps for TX, 500 ps for RX)
    ADF4382A_SetPhaseShift(&lo_manager, 500, 500);

    // Strobe to apply phase shifts
    ADF4382A_StrobePhaseShift(&lo_manager, 0); // TX device
    ADF4382A_StrobePhaseShift(&lo_manager, 1); // RX device
    if (ret != ADF4382A_MANAGER_OK) {
        printf("LO Manager initialization failed: %d\n", ret);
        Error_Handler();
    }

    // Check initial lock status
    bool tx_locked, rx_locked;
    ret = ADF4382A_CheckLockStatus(&lo_manager, &tx_locked, &rx_locked);
    if (ret == ADF4382A_MANAGER_OK) {
        printf("Initial Lock Status - TX: %s, RX: %s\n",
               tx_locked ? "LOCKED" : "UNLOCKED",
               rx_locked ? "LOCKED" : "UNLOCKED");
    }
    // Wait for both LOs to lock
        uint32_t lock_timeout = 0;
        while (!(tx_locked && rx_locked) && lock_timeout < 100) {
            HAL_Delay(100);
            ADF4382A_CheckLockStatus(&lo_manager, &tx_locked, &rx_locked);
            lock_timeout++;

            if (lock_timeout % 10 == 0) {
                printf("Waiting for LO lock... TX: %s, RX: %s\n",
                       tx_locked ? "LOCKED" : "UNLOCKED",
                       rx_locked ? "LOCKED" : "UNLOCKED");
            }
        }

        if (tx_locked && rx_locked) {
            printf("Both LOs locked successfully!\n");
            printf("Synchronization ready - 60 MHz clocks on SYNCP/SYNCN pins\n");
            // - 60 MHz phase-aligned clocks on SYNCP/SYNCN pins
            // - SYNC pin connected for triggering

            // When ready to synchronize:
            ADF4382A_TriggerTimedSync(&lo_manager);
            // At this point, the SYNC pin can be toggled to trigger synchronization
        } else {
            printf("LO lock timeout! TX: %s, RX: %s\n",
                   tx_locked ? "LOCKED" : "UNLOCKED",
                   rx_locked ? "LOCKED" : "UNLOCKED");
        }
  // check if there is a lock
  if(HAL_GPIO_ReadPin (ADF4382_TX_LKDET_GPIO_Port, ADF4382_TX_LKDET_Pin))
  {
      // Set The LED_1 ON!
      HAL_GPIO_WritePin(LED_1_GPIO_Port, LED_1_Pin, GPIO_PIN_SET);
  }
  else
  {
      // Else .. Turn LED_1 OFF!
      HAL_GPIO_WritePin(LED_1_GPIO_Port, LED_1_Pin, GPIO_PIN_RESET);
  }
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

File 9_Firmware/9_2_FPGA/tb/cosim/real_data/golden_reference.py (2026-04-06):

#!/usr/bin/env python3
"""
golden_reference.py — AERIS-10 FPGA bit-accurate golden reference model

Uses ADI CN0566 Phaser radar data (10.525 GHz X-band FMCW) to validate
the FPGA signal processing pipeline stage by stage:

    ADC → DDC (NCO+mixer+CIC+FIR) → Range FFT → Doppler FFT → Detection

The model replicates exact RTL fixed-point arithmetic (bit widths, truncation,
rounding, saturation) so outputs can be compared bit-for-bit against Icarus
Verilog simulation results.

Generates .hex stimulus files for RTL testbenches and .npy reference files
for comparison.

Usage:
    python3 golden_reference.py [--frame N] [--plot]
"""

import numpy as np
import os
import sys
import argparse

# ===========================================================================
# Configuration — exact match to RTL parameters
# ===========================================================================

# ADC
ADC_BITS = 8                    # ad9484: 8-bit unsigned

# NCO
NCO_PHASE_WIDTH = 32
NCO_PHASE_INC = 0x4CCCCCCD     # 120 MHz IF at 400 MHz Fs
NCO_LUT_SIZE = 64               # Quarter-wave sine LUT entries
NCO_OUT_BITS = 16                # Signed 16-bit sin/cos output

# Mixer
MIXER_IN_BITS = 18               # ADC sign-extended to 18-bit
MIXER_PRODUCT_BITS = 34          # 18 x 16 = 34
MIXER_TRUNCATE_SHIFT = 16        # mixed_i[33:16] fed to CIC

# CIC
CIC_STAGES = 5
CIC_DECIMATION = 4
CIC_DIFFERENTIAL_DELAY = 1
CIC_ACC_WIDTH = 48
CIC_COMB_WIDTH = 28
CIC_GAIN_SHIFT = 10              # >>> 10 to normalize 4^5 = 1024
CIC_OUT_BITS = 18                # Saturated to signed 18-bit

# FIR
FIR_TAPS = 32
FIR_COEFF_WIDTH = 18
FIR_DATA_WIDTH = 18
FIR_ACCUM_WIDTH = 36
# Coefficients from fir_lowpass.v (18-bit signed hex, 18'sh notation)
FIR_COEFFS_HEX = [
    0x000AD, 0x000CE, 0x3FD87, 0x002A6,
    0x000E0, 0x3F8C0, 0x00A45, 0x3FD82,
    0x3F0B5, 0x01CAD, 0x3EE59, 0x3E821,
    0x04841, 0x3B340, 0x3E299, 0x1FFFF,
    0x1FFFF, 0x3E299, 0x3B340, 0x04841,
    0x3E821, 0x3EE59, 0x01CAD, 0x3F0B5,
    0x3FD82, 0x00A45, 0x3F8C0, 0x000E0,
    0x002A6, 0x3FD87, 0x000CE, 0x000AD,
]

# DDC output interface
DDC_OUT_BITS = 16                # 18 → 16 bit with rounding + saturation

# FFT (Range)
FFT_SIZE = 1024
FFT_DATA_W = 16
FFT_INTERNAL_W = 32
FFT_TWIDDLE_W = 16

# Doppler — dual 16-pt FFT architecture
DOPPLER_FFT_SIZE = 16            # per sub-frame
DOPPLER_TOTAL_BINS = 32          # total output (2 sub-frames x 16)
DOPPLER_RANGE_BINS = 64
DOPPLER_CHIRPS = 32
CHIRPS_PER_SUBFRAME = 16
DOPPLER_WINDOW_TYPE = 0          # Hamming

# 16-point Hamming window coefficients from doppler_processor.v (Q15)
HAMMING_Q15 = [
    0x0A3D, 0x0E5C, 0x1B6D, 0x3088,
    0x4B33, 0x6573, 0x7642, 0x7F62,
    0x7F62, 0x7642, 0x6573, 0x4B33,
    0x3088, 0x1B6D, 0x0E5C, 0x0A3D,
]

# ADI dataset parameters
ADI_SAMPLE_RATE = 4e6            # 4 MSPS
ADI_IF_FREQ = 100e3             # 100 kHz IF
ADI_RF_FREQ = 9.9e9             # 9.9 GHz
ADI_CHIRP_BW = 500e6            # 500 MHz
ADI_RAMP_TIME = 300e-6          # 300 us
ADI_NUM_CHIRPS = 256
ADI_SAMPLES_PER_CHIRP = 1079

# AERIS-10 parameters
AERIS_FS = 400e6                 # 400 MHz ADC clock
AERIS_IF = 120e6                 # 120 MHz IF


# ===========================================================================
# Helper: Convert hex to signed integer
# ===========================================================================
def hex_to_signed(val, bits):
    """Convert unsigned hex value to signed integer."""
    if val >= (1 << (bits - 1)):
        return val - (1 << bits)
    return val


def signed_to_hex(val, bits):
    """Convert signed integer to hex string (no prefix)."""
    if val < 0:
        val = val + (1 << bits)
    return format(val & ((1 << bits) - 1), f'0{(bits + 3) // 4}X')


def saturate(val, bits):
    """Saturate signed value to fit in 'bits' width."""
    max_pos = (1 << (bits - 1)) - 1
    max_neg = -(1 << (bits - 1))
    if val > max_pos:
        return max_pos
    if val < max_neg:
        return max_neg
    return int(val)
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

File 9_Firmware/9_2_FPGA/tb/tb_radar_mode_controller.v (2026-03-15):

`timescale 1ns / 1ps

module tb_radar_mode_controller;

    // ── Parameters ─────────────────────────────────────────────
    localparam CLK_PERIOD = 10.0;  // 100 MHz

    // Use much shorter timing for simulation (100x faster)
    localparam SIM_LONG_CHIRP   = 30;
    localparam SIM_LONG_LISTEN  = 137;
    localparam SIM_GUARD        = 175;
    localparam SIM_SHORT_CHIRP  = 5;
    localparam SIM_SHORT_LISTEN = 175;

    // Use small scan size for simulation
    localparam SIM_CHIRPS     = 4;
    localparam SIM_ELEVATIONS = 3;
    localparam SIM_AZIMUTHS   = 2;

    // ── Signals ────────────────────────────────────────────────
    reg         clk;
    reg         reset_n;
    reg  [1:0]  mode;
    reg         stm32_new_chirp;
    reg         stm32_new_elevation;
    reg         stm32_new_azimuth;
    reg         trigger;

    wire        use_long_chirp;
    wire        mc_new_chirp;
    wire        mc_new_elevation;
    wire        mc_new_azimuth;
    wire [5:0]  chirp_count;
    wire [5:0]  elevation_count;
    wire [5:0]  azimuth_count;
    wire        scanning;
    wire        scan_complete;

    // ── Test bookkeeping ───────────────────────────────────────
    integer pass_count;
    integer fail_count;
    integer test_num;
    integer csv_file;
    integer i;

    // Edge detection helpers for auto-scan counting
    reg mc_new_chirp_prev;
    reg mc_new_elevation_prev;
    reg mc_new_azimuth_prev;
    integer chirp_toggles;
    integer elevation_toggles;
    integer azimuth_toggles;
    integer scan_completes;

    // Saved values for toggle checks
    reg saved_mc_new_chirp;
    reg saved_mc_new_elevation;
    reg saved_mc_new_azimuth;

    // ── Clock ──────────────────────────────────────────────────
    always #(CLK_PERIOD/2) clk = ~clk;

    // ── DUT ────────────────────────────────────────────────────
    radar_mode_controller #(
        .CHIRPS_PER_ELEVATION  (SIM_CHIRPS),
        .ELEVATIONS_PER_AZIMUTH(SIM_ELEVATIONS),
        .AZIMUTHS_PER_SCAN     (SIM_AZIMUTHS),
        .LONG_CHIRP_CYCLES     (SIM_LONG_CHIRP),
        .LONG_LISTEN_CYCLES    (SIM_LONG_LISTEN),
        .GUARD_CYCLES          (SIM_GUARD),
        .SHORT_CHIRP_CYCLES    (SIM_SHORT_CHIRP),
        .SHORT_LISTEN_CYCLES   (SIM_SHORT_LISTEN)
    ) uut (
        .clk                (clk),
        .reset_n            (reset_n),
        .mode               (mode),
        .stm32_new_chirp    (stm32_new_chirp),
        .stm32_new_elevation(stm32_new_elevation),
        .stm32_new_azimuth  (stm32_new_azimuth),
        .trigger            (trigger),
        .use_long_chirp     (use_long_chirp),
        .mc_new_chirp       (mc_new_chirp),
        .mc_new_elevation   (mc_new_elevation),
        .mc_new_azimuth     (mc_new_azimuth),
        .chirp_count        (chirp_count),
        .elevation_count    (elevation_count),
        .azimuth_count      (azimuth_count),
        .scanning           (scanning),
        .scan_complete      (scan_complete)
    );

    // ── Check task ─────────────────────────────────────────────
    task check;
        input cond;
        input [511:0] label;
        begin
            test_num = test_num + 1;
            if (cond) begin
                $display("[PASS] Test %0d: %0s", test_num, label);
                pass_count = pass_count + 1;
            end else begin
                $display("[FAIL] Test %0d: %0s", test_num, label);
                fail_count = fail_count + 1;
            end
        end
    endtask

    // ── Helper: apply reset ────────────────────────────────────
    task apply_reset;
        begin
            reset_n             = 0;
            mode                = 2'b11;  // reserved = safe idle
            stm32_new_chirp     = 0;
            stm32_new_elevation = 0;
            stm32_new_azimuth   = 0;
            trigger             = 0;
            repeat (4) @(posedge clk);
            reset_n = 1;
            @(posedge clk); #1;
        end
    endtask

    // ── Stimulus ───────────────────────────────────────────────
    initial begin
        $dumpfile("tb_radar_mode_controller.vcd");
        $dumpvars(0, tb_radar_mode_controller);

        clk        = 0;
        pass_count = 0;
        fail_count = 0;
        test_num   = 0;

        // ════════════════════════════════════════════════════════
        // TEST GROUP 1: Reset behaviour
        // ════════════════════════════════════════════════════════
        $display("\n--- Test Group 1: Reset Behaviour ---");
        apply_reset;

        reset_n = 0;
        repeat (4) @(posedge clk); #1;
        check(use_long_chirp === 1'b1,     "use_long_chirp=1 after reset");
        check(mc_new_chirp === 1'b0,       "mc_new_chirp=0 after reset");
        check(mc_new_elevation === 1'b0,   "mc_new_elevation=0 after reset");
        check(mc_new_azimuth === 1'b0,     "mc_new_azimuth=0 after reset");
        check(chirp_count === 6'd0,        "chirp_count=0 after reset");
        check(elevation_count === 6'd0,    "elevation_count=0 after reset");
        check(azimuth_count === 6'd0,      "azimuth_count=0 after reset");
        check(scanning === 1'b0,           "scanning=0 after reset");
        check(scan_complete === 1'b0,      "scan_complete=0 after reset");
        reset_n = 1;
        @(posedge clk); #1;

        // ════════════════════════════════════════════════════════
        // TEST GROUP 2: STM32 pass-through mode (mode 00)
        // The DUT uses XOR toggle detection: when stm32_new_chirp
        // changes from its previous value, the DUT detects it.
        // We toggle-and-hold (don't pulse) to get exactly one detection.
        // ════════════════════════════════════════════════════════
        $display("\n--- Test Group 2: STM32 Pass-through (mode 00) ---");
        apply_reset;
        mode = 2'b00;
        @(posedge clk); #1;

        // Save current mc_new_chirp
        saved_mc_new_chirp = mc_new_chirp;

        // Toggle stm32_new_chirp (0→1, hold at 1)
        stm32_new_chirp = 1'b1;
        // Wait 2 cycles: 1 for prev register update, 1 for XOR→main FSM
        @(posedge clk); @(posedge clk); #1;

        check(mc_new_chirp !== saved_mc_new_chirp,
              "mc_new_chirp toggles on stm32 chirp change");
        check(chirp_count === 6'd1, "chirp_count incremented to 1");

        // Toggle again (1→0, hold at 0) — second chirp
        saved_mc_new_chirp = mc_new_chirp;
        stm32_new_chirp = 1'b0;
        @(posedge clk); @(posedge clk); #1;

        check(mc_new_chirp !== saved_mc_new_chirp,
              "mc_new_chirp toggles again");
        check(chirp_count === 6'd2, "chirp_count incremented to 2");
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

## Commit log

2026-03-13 fix(firmware): propagate gy85 i2c failures
    [main.cpp]
2026-03-15 Add 3 missing FPGA modules with enhanced testbenches (168/168 pass)
    Implement the 3 modules identified as missing during repo audit:
    - matched_filter_processing_chain: behavioral FFT-based pulse compression
    - range_bin_decimator: 1024→64 bin decimation with 3 modes + start_bin
    - radar_mode_controller: 4-mode beam/chirp controller
    Wire radar_mode_controller into radar_receiver_final.v to drive the
    previously-undriven use_long_chirp and mc_new_* signals.
    Implement start_bin functionality in range_bin_decimator (was dead code
    in the original interface contract — now skips N input bins before
    decimation for region-of-interest selection).
    Add comprehensive testbenches with Tier 1 confidenc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
    [matched_filter_processing_chain.v, radar_mode_controller.v, tb_matched_filter_processing_chain.v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]
2026-03-16 Regenerate chirp .mem files, add USB testbench, convert radar_system_tb to Verilog-2001
    - Regenerate all 10 chirp .mem files with correct AERIS-10 parameters
    (gen_chirp_mem.py: phase = pi*chirp_rate*t^2, 4 segments x 1024)
    - Add gen_chirp_mem.py script for reproducible .mem generation
    - Add tb_usb_data_interface.v testbench (39/39 PASS)
    - Convert radar_system_tb.v from SystemVerilog to Verilog-2001:
    replace $sin() with LUT, inline integer decl, SVA with procedural checks
    - All testbenches pass: integration 10/10, MF 3/3, multi-seg 32/32,
    DDC 4/4, Doppler 14/14, USB 39/39, .mem validation 56/56
    - Vivado timing closure confirmed: WNS=+0.021ns on xc7a100t-csg324-1
    [radar_system_tb.v]
2026-03-19 Fix Bug #11 (platform SPI transmit-only), FPGA B2 (chirp BRAM migration), FPGA B3 (DSP48 pipelining)
    Bug #11: platform_noos_stm32.c used HAL_SPI_Transmit instead of
    HAL_SPI_TransmitReceive — reads returned garbage. Changed to in-place
    full-duplex. Dead code (never called), fixed per audit recommendation.
    Test added: test_bug11_platform_spi_transmit_only.c. Mock infrastructure
    updated with SPI spy types. All 11 firmware tests pass.
    FPGA B2: Migrated long_chirp_lut[0:3599] from ~700 lines of hardcoded
    assignments to BRAM with (* ram_style = "block" *) attribute and
    $readmemh("long_chirp_lut.mem"). Added sync-only read block for proper
    BRAM inference. 1-cycle read latency introduced. short_c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
    [platform_noos_stm32.c, plfm_chirp_controller.v, stm32_hal_mock.c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]
2026-03-19 FIR DSP48 pipelining (BREG+MREG) + matched filter BRAM migration with overlap cache
    FIR: Add coeff_reg/mult_reg pipeline stages to fix 68 DPIP-1 + 35 DPOP-2
    DRC warnings. Valid pipeline widened 7→9 bits (+2 cycle latency).
    Matched filter: Migrate input_buffer_i/q from register arrays to BRAM
    (~33K FF savings). Overlap-save uses register cache captured during
    ST_PROCESSING to avoid BRAM read/write conflicts during overlap copy.
    New ST_OVERLAP_COPY state writes cached tail samples back sequentially.
    Both changes pass 18/18 FPGA regression. Golden data regenerated for
    +2 FIR latency baseline.
    [rx_final_doppler_out.csv]
2026-04-06 fix(scripts): make Vivado TCL scripts portable and update RTL file lists
    - Replace hardcoded /home/jason-stone/ paths with [info script]-relative
    path resolution in all 9 scripts (build17-21, insert_ila_probes,
    program_fpga, ila_capture, run_cdc_and_netlist)
    - Point constraint references at tracked XDC files instead of
    untracked synth_only.xdc
    - Remove six phantom RTL entries (chirp_lut_init.v, fft_1024_forward.v,
    fft_1024_inverse.v, level_shifter_interface.v, lvds_to_cmos_400m.v,
    usb_packet_analyzer.v)
    - Add six existing modules to file lists (rx_gain_control.v,
    mti_canceller.v, cfar_ca.v, fpga_self_test.v, xfft_16.v,
    adc_clk_mmcm.v)
    Closes #38
2026-04-06 fix(test,docs): remove dead xfft_32 files, update test infra for dual-16 FFT, add regression guide
    - Remove xfft_32.v, tb_xfft_32.v, and fft_twiddle_32.mem (dead code
    since PR #33 moved Doppler to dual 16-pt FFT architecture)
    - Update run_regression.sh: xfft_16 in PROD_RTL, remove xfft_32 from
    EXTRA_RTL and all compile commands
    - Update tb_fft_engine.v to test with N=16 / fft_twiddle_16.mem
    - Update validate_mem_files.py: validate fft_twiddle_16.mem instead of 32
    - Update testbenches and golden data from main_cleanup branch to match
    dual-16 architecture (tb_doppler_cosim, tb_doppler_realdata,
    tb_fullchain_realdata, tb_fullchain_mti_cfar_realdata, tb_system_e2e,
    radar_receiver_final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
    [tb_system_e2e.v]

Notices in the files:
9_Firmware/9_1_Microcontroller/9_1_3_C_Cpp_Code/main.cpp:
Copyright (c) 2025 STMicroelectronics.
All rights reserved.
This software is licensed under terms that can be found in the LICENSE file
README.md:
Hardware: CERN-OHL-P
